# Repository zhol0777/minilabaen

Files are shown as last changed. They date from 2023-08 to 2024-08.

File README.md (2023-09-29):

# minilabaen

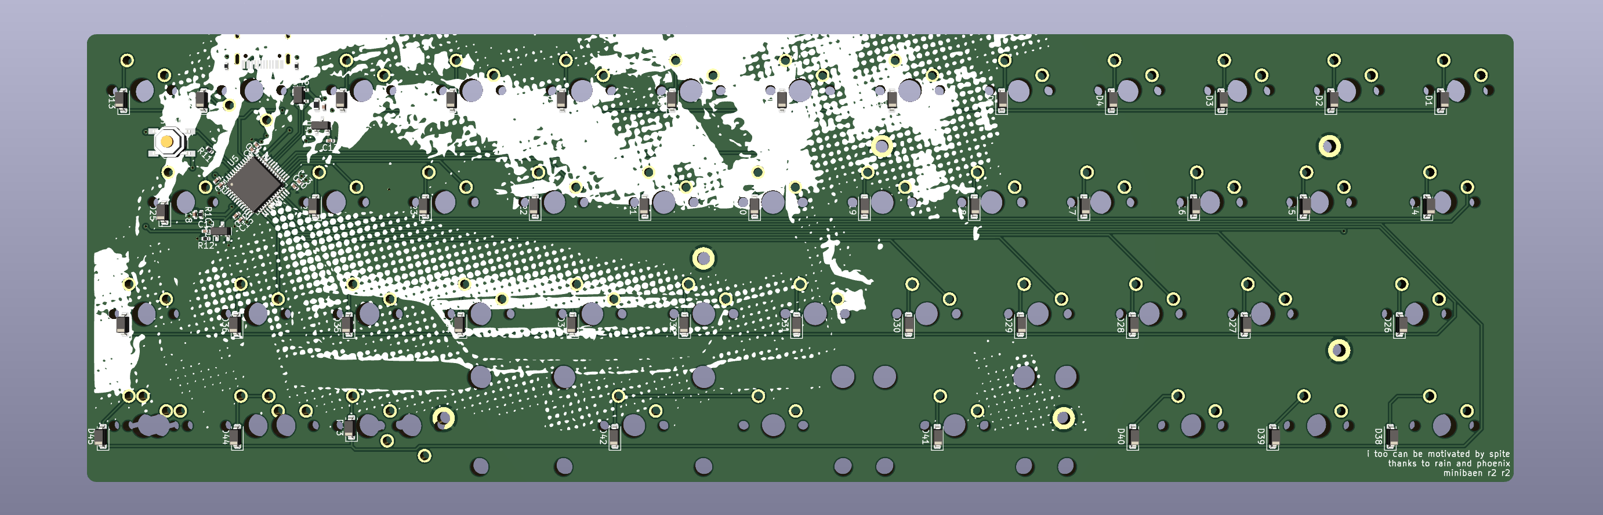
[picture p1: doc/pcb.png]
back of pcb


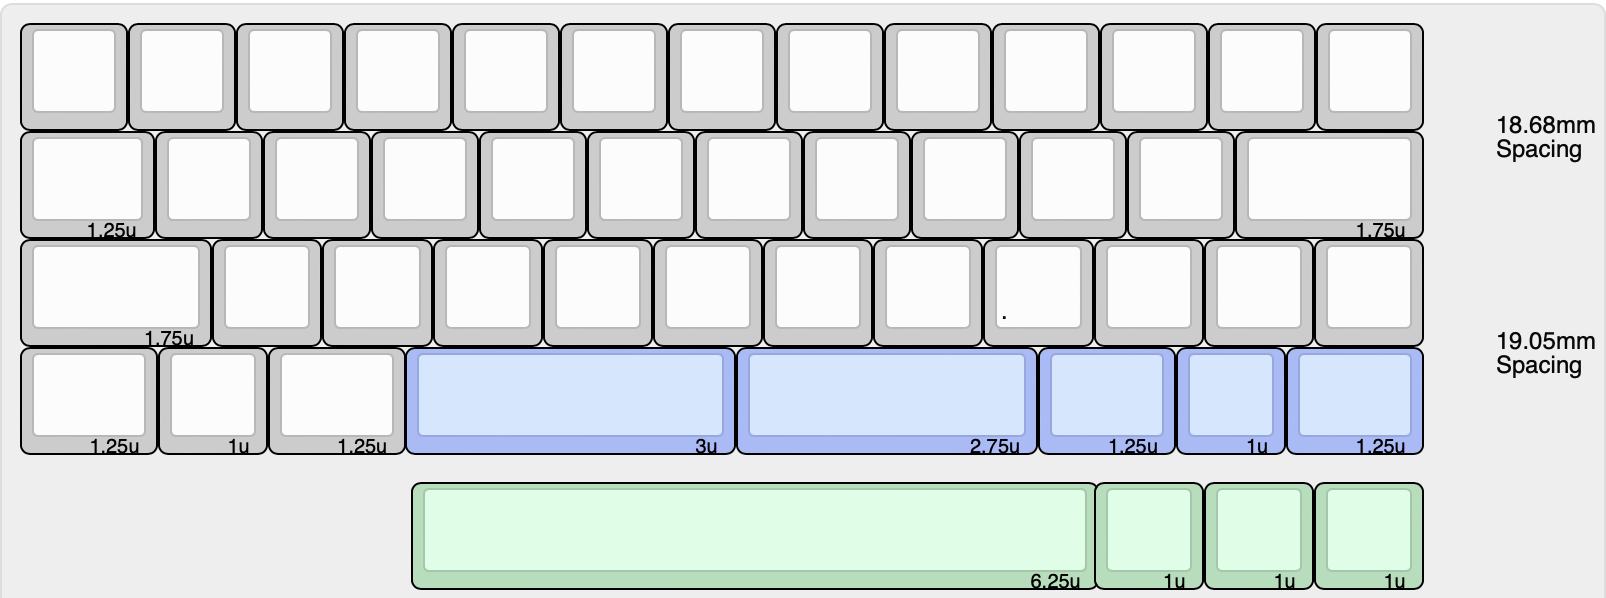
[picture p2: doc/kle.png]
keyboard layout showing what appears to be a 13u layout but 12.75u bottom row


[kle](http://www.keyboard-layout-editor.com/#/gists/a9f61f5347eb8cae020ee2f3067dfd0b)

made in kicad 7.99 nightly, sorry

staggered layout with minibaen spacing (18.68mm x 19.05mm) on the top two rows (to handle keysets with boycott kitting)
19.05mm x 19.05mm spacing on the bottom alpha row, and modifier key row
modifier key row supports 1.25/1/1.25/2.75/3/1.25/1/1.25 layout for spacebar kits designed by people who included only a single 3u bar, and jetvan

based on minibaen r2, extraneous files from ortho minibaen have not been cleared out so uhhhh watch out.
edge cuts, usb port position, and some tray mount points are lifted from there.

gerbers and dxf for plates for tray mount and coriander top mount are provided.

pcb prototype was confirmed functional as of sept. 27, 2023. plates are awaiting prototyping still.
the firmware source needs some fixes and updates, will provide those shortly.

## thanks

* stm32f072 schematic is courtesy xphoenixd
* kiser for suggesting leaving normal spacing on bottom alpha row
* rain on basic tips on how to generate plate files easily, as well as part number for ESD chip
  * islandworks, matt, and mel for suggesting I don't use "ballsack" ESD chip 

## issues

* SW12 needs to be flipped to north facing, otherwise the pins interfere with usb. if you intend on using this in tray mount, you may need to clip the switch legs.
* SW43 needs to be flipped to north facing, to prevent interference with bottom right tray mount point.
* some mount points are excluded due to interference with components or switches
  * one of the mount points on the 3U bar cannot be screwed in since it is in the same location as the 3u stabilizer. the best way to deal with this is to use GMK 3U bars, which contain stems for 2U stabilizers as well.

have fun!

zhol

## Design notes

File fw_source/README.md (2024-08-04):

# mkh bully

* Keyboard Maintainer: [zhol0777](https://github.com/zhol0777)
* Hardware Supported: STM32F072
* Hardware Availability: [Open-source](https://github.com/zhol0777/minilabaen/)

Make example for this keyboard (after setting up your build environment):

    qmk compile -kb zhol/minilabaen -km default

Flashing example for this keyboard:

    qmk flash -kb zhol/minilabaen -km default

See the [build environment setup](https://docs.qmk.fm/#/getting_started_build_tools) and the [make instructions](https://docs.qmk.fm/#/getting_started_make_guide) for more information. Brand new to QMK? Start with our [Complete Newbs Guide](https://docs.qmk.fm/#/newbs).

## Bootloader

Enter the bootloader in 3 ways:

* **Bootmagic reset**: Hold down the key at (0,0) in the matrix (usually the top left key or Escape) and plug in the keyboard
* **Physical reset button**: Briefly press the button on the back of the PCB - some may have pads you must short instead
* **Keycode in layout**: Press the key mapped to `QK_BOOT` if it is available

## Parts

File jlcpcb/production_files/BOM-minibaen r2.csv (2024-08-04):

Comment | Designator | Footprint | LCSC
10nF | C12 | C_0402_1005Metric | C15195
USB_C_Receptacle_USB2.0 | J1 | USB_C_Receptacle_HRO_TYPE-C-31-M-12 | C165948
4.7uF | C13,C14,C19 | C_0402_1005Metric | C23733
100k | R12 | R_0402_1005Metric | C25741
10k | R10,R11 | R_0402_1005Metric | C25744
5k1 | R8,R9 | R_0402_1005Metric | C25905
PRTR5V0U2X | D46 | SOT-143 | C2827688
100nF | C10,C11,C8,C9 | C_0402_1005Metric | C307331
SW_Push | SW50 | SW_SPST_TL3342 | C318884
1uF | C15,C16,C17,C18 | C_0402_1005Metric | C52923
XC6206PxxxMR | U4 | SOT-23 | C5446
D_Small | D1,D10,D11,D12,D13,D14,D15,D16,D17,D18,D19,D2,D20,D21,D22,D23,D24,D25,D26,D27,D28,D29,D3,D30,D31,D32,D33,D34,D35,D36,D37,D38,D39,D4,D40,D41,D42,D43,D44,D45,D5,D6,D7,D8,D9 | D_SOD-123 | C81598
2N7002 | Q1 | SOT-23 | C8545
500mA | F2 | Fuse_0603_1608Metric | C883095
STM32F072C8Tx | U5 | LQFP-48_7x7mm_P0.5mm | C915660

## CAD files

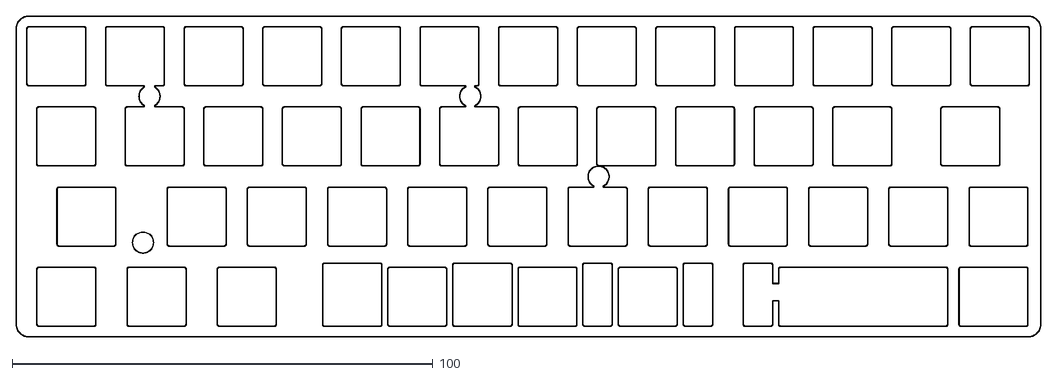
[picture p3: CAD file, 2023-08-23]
plate_files/tray_edge_cut.dxf
243.4 x 76.2

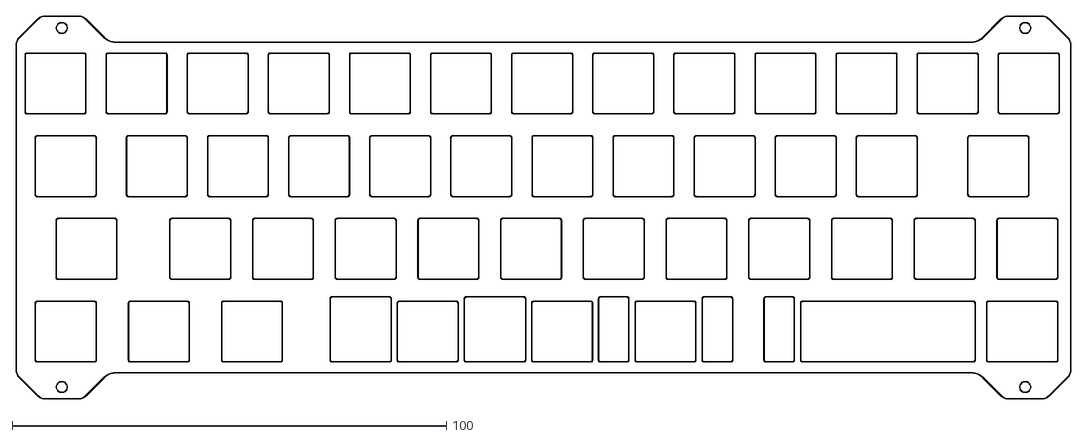
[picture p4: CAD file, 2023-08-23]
plate_files/coriander_edge_cut.dxf
242.9 x 88.2

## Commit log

2023-03-29 add jlcpcb plugin with complete bom, redo bottom row layout
    [BOM-minibaen r2.csv, designators.csv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]
2023-05-07 fix 3v3 routing, add firmware
    [BOM-minibaen r2.csv, bom.csv, designators.csv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]
2023-08-23 add plate files
    [coriander_edge_cut.dxf, tray_edge_cut.dxf]
2023-09-29 confirm pcb works
